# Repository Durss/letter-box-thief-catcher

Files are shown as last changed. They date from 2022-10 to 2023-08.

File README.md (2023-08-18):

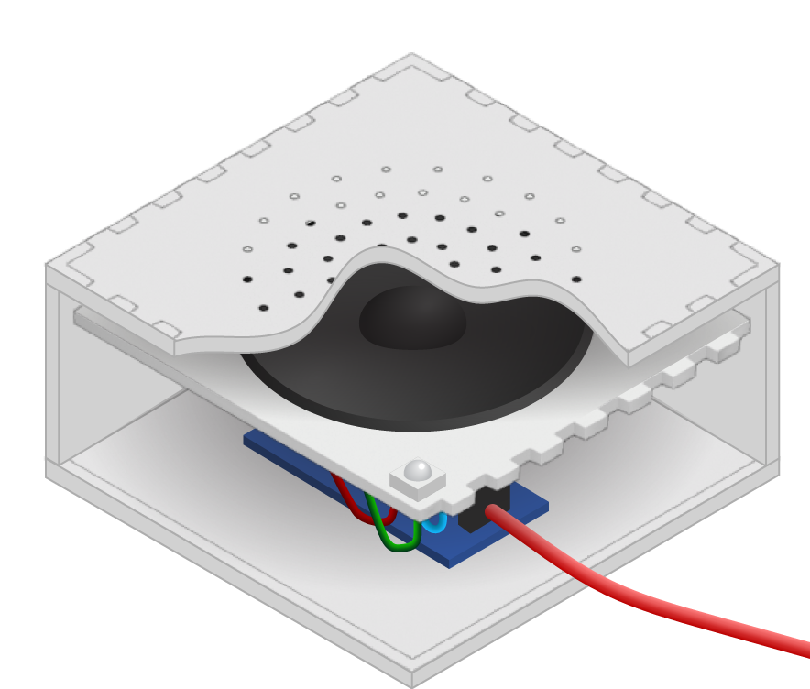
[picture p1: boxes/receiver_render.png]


# Da heck is that?
A thief is starting to hammer my balls stealing stuff from the mailboxes of my building, including mine.\
Stealing my credit card being the red line he shoudln't have crossed, and as we say `Don't fuck with a developer`, I've made this simple arduino project consisting of a BLE emiter I put inside the mailbox and a receiver inside my flat.\
When the mailbox is opened, the receiver knows and screams sounds on a speaker.\
As soon as the receiver screams, I'll run down and god knows what will happen then!\
\
It's made to use as low energy as possible so it can run for weeks on a Lipo battery.\
There is no actual BLE connection, the emitter simply changes the bluetooth connexion name to `letterbox-open` or `letterbox-closed` depending on the door state.\
It goes to deep sleep for 2 minutes and wakes up for only 10s just to tell the receivier that battery is still alive.\
If the door is opened when in deep sleep, an interrupt wakes the board up so the receiver knows the door has been opened as fast as possible.\
\
I'm lucky enough to get my flat just above the mailboxes so the bluetooth connection can be established between the mailbox and my home.\
If you don't, this won't help you for this use case but it may for something else, who knows...

# Component parts
- 1 [Particle Xenon](https://docs.particle.io/xenon/) board. These are discontinued, but it should run on any other kind of [Particle Boards](https://www.particle.io/devices/) as long as it supports bluetooth and can most probably run on ESP32 boards with probably some tweaks.
- 1 [speaker](https://www.adafruit.com/product/1313).
- 1 [DFPlayer mini](https://wiki.dfrobot.com/DFPlayer_Mini_SKU_DFR0299) that plays MP3s on the speaker.
- 1 [lipo battery](https://www.adafruit.com/product/2011) to power the board. The boards includes a lipo charger, just plug it to a USB wall adapter.
- 1 [micro switch](https://www.sparkfun.com/products/13014) that detects the door opening and wakes up the arduino board.
- 1 [Piranha RGB LED](https://www.adafruit.com/product/1451) (or any RGB led but it might not fit in the [given box](#boxes)
- 1 micro SD card to store MP3s
- 3 resistors (330Ω)
- [Optional] 1 or 2 [bluetooth antennas](https://www.adafruit.com/product/2308) to expand bluetooth range *(the one linked is for wifi but it should work also for BLE)*
- [Optional] 1 [protoboard](https://www.adafruit.com/product/4786) to solder components on it ([see schematics](#schematics))
- [Optional] [headers](https://www.adafruit.com/product/4160) if you don't want to solder the arduino board and the DFPlayer mini on the protoboard.

# Build
Build and upload emitter and receiver codes on their Xenon board.\
For that, you may want to use [VSCode](https://code.visualstudio.com) with [Particle Workbench](https://www.particle.io/workbench/).\
Also install [Particle CLI](https://docs.particle.io/getting-started/developer-tools/cli/) that installs necessary drivers.\

# Flash particle board
Open "Emitter" or "Receiver" folders in VScode. Not the root folder.\
Plug the board via USB, press `Ctrl+Shift+P` and select `Particle: Flash application (local)`. This will flash the board. Use `Particle: Serial monitor to get logs`.

# Boxes
If you have access to a laser cutter, you'll find SVG files to cut boxes for the emitter and the receiver under [boxes](https://github.com/Durss/mailbox-thief-catcher/tree/main/boxes) folder.

## Emiter:
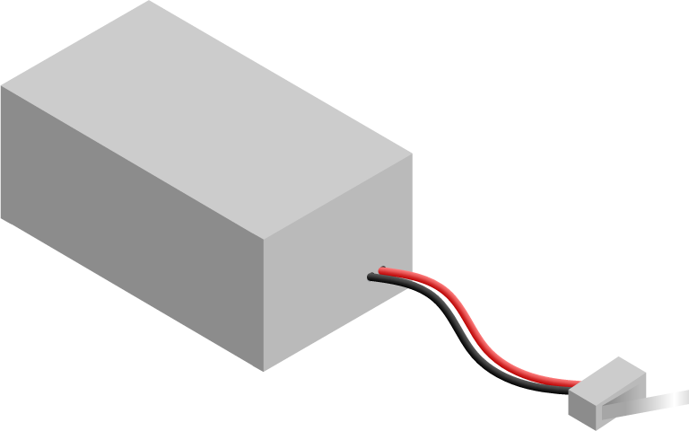
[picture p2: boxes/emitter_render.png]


## Receiver:


# Schematics
## Receiver
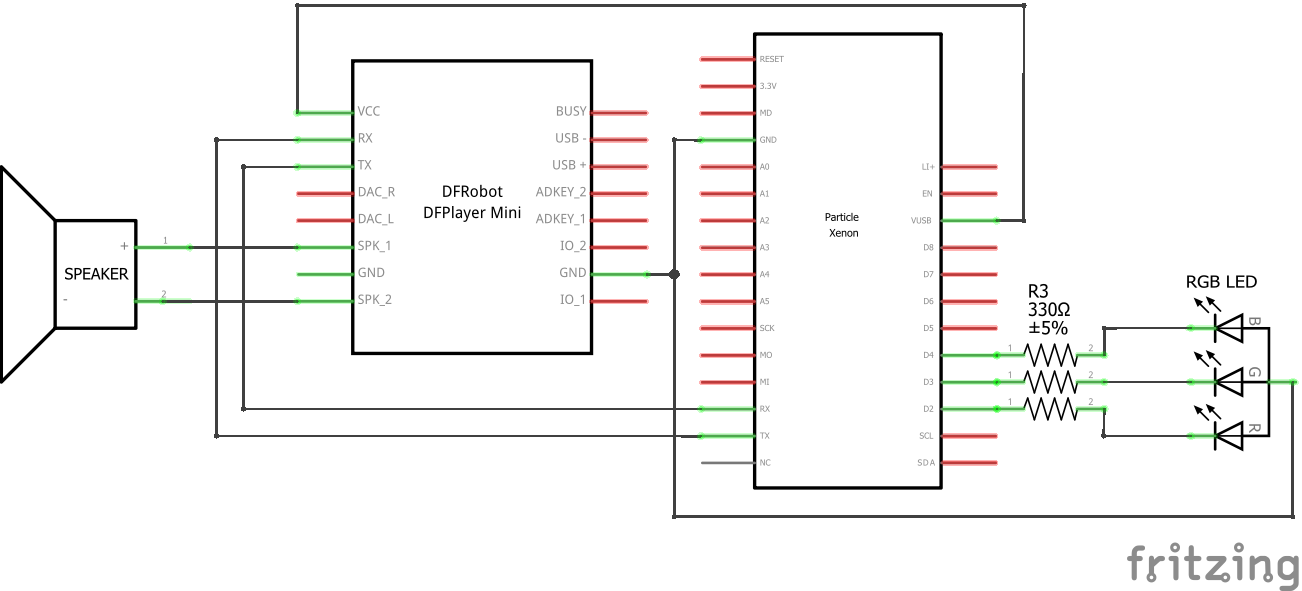
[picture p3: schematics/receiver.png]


## Emitter
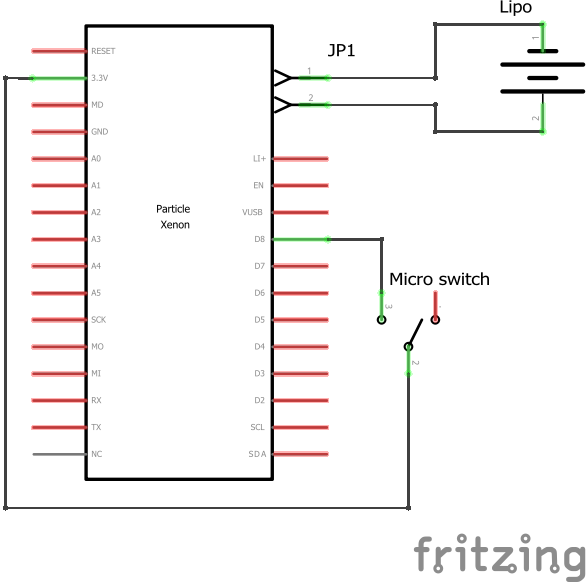
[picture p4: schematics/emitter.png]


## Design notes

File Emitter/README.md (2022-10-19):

# Emitter

A Particle project named Emitter

## Welcome to your project!

Every new Particle project is composed of 3 important elements that you'll see have been created in your project directory for Emitter.

#### ```/src``` folder:  
This is the source folder that contains the firmware files for your project. It should *not* be renamed. 
Anything that is in this folder when you compile your project will be sent to our compile service and compiled into a firmware binary for the Particle device that you have targeted.

If your application contains multiple files, they should all be included in the `src` folder. If your firmware depends on Particle libraries, those dependencies are specified in the `project.properties` file referenced below.

#### ```.ino``` file:
This file is the firmware that will run as the primary application on your Particle device. It contains a `setup()` and `loop()` function, and can be written in Wiring or C/C++. For more information about using the Particle firmware API to create firmware for your Particle device, refer to the [Firmware Reference](https://docs.particle.io/reference/firmware/) section of the Particle documentation.

#### ```project.properties``` file:  
This is the file that specifies the name and version number of the libraries that your project depends on. Dependencies are added automatically to your `project.properties` file when you add a library to a project using the `particle library add` command in the CLI or add a library in the Desktop IDE.

## Adding additional files to your project

#### Projects with multiple sources
If you would like add additional files to your application, they should be added to the `/src` folder. All files in the `/src` folder will be sent to the Particle Cloud to produce a compiled binary.

#### Projects with external libraries
If your project includes a library that has not been registered in the Particle libraries system, you should create a new folder named `/lib/<libraryname>/src` under `/<project dir>` and add the `.h`, `.cpp` & `library.properties` files for your library there. Read the [Firmware Libraries guide](https://docs.particle.io/guide/tools-and-features/libraries/) for more details on how to develop libraries. Note that all contents of the `/lib` folder and subfolders will also be sent to the Cloud for compilation.

## Compiling your project

When you're ready to compile your project, make sure you have the correct Particle device target selected and run `particle compile <platform>` in the CLI or click the Compile button in the Desktop IDE. The following files in your project folder will be sent to the compile service:

- Everything in the `/src` folder, including your `.ino` application file
- The `project.properties` file for your project
- Any libraries stored under `lib/<libraryname>/src`

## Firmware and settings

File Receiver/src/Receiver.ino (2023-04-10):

#include "Particle.h"

SYSTEM_THREAD(ENABLED);
SYSTEM_MODE(MANUAL);

#define MP3_Start_Byte 0x7E
#define MP3_Version_Byte 0xFF
#define MP3_Command_Length 0x06
#define MP3_End_Byte 0xEF
#define MP3_Acknowledge 0x00 //Returns info with command 0x41 [0x01: info, 0x00: no info]

const uint LOST_TIMEOUT = 6 * 60 * 1000;//Duration after which the emitter is considered lost if it didn't show up
const char *BLE_OPENED_NAME = "letterbox-opened";//BLE name when door is opened
const char *BLE_CLOSED_NAME = "letterbox-closed";//BLE name when door is closed

// EXAMPLE
BleScanParams scanParams;


bool doorOpened = false;
bool toogle = true;
uint lastAliveMs = 0;
int rPin = D2;
int gPin = D3;
int bPin = D4;

void setup()
{
	Serial.begin(9600);
	Serial1.begin(9600);
	Serial.println("Serial begin");
	/*
	// delay(2000);
	Serial.println("Init player");
	MP3ExecuteCmd(0x3F, 0, 0); // Send request for initialization parameters

	// Wait until initialization parameters are received (10 bytes)
	while (Serial1.available() < 10)
	{
		Serial.println(Serial1.read());
		delay(100); // Pretty long delays between succesive commands needed (not always the same)
	}
	//*/
	
	scanParams.active = 0;
	scanParams.size = sizeof(BleScanParams);
	int res = BLE.getScanParameters(&scanParams);
	Serial.print("RESULT: ");
	Serial.println(res);

	pinMode(rPin, OUTPUT);
	pinMode(gPin, OUTPUT);
	pinMode(bPin, OUTPUT);

	analogWrite(rPin, 0);
	analogWrite(gPin, 255);
	analogWrite(bPin, 255);

	MP3ExecuteCmd(0x06, 0, 25);//Set volume from 0 to 33

	analogWrite(rPin, 0);
	analogWrite(gPin, 0);
	analogWrite(bPin, 0);

	Serial.println("Play sound");
	MP3ExecuteCmd(0x0F, 1, 1);//Play start sound
	delay(2000);
}

void loop()
{
	/* Demo mode
	delay(5000);
	analogWrite(rPin, 0);
	analogWrite(gPin, 255);
	analogWrite(bPin, 255);
	delay(500);
	MP3ExecuteCmd(0x0F, 1, 2);//Play sound N°1

	delay(5000);

	analogWrite(rPin, 0);
	analogWrite(gPin, 0);
	analogWrite(bPin, 0);
	//*/

	//*
	MP3OnMessage();

	if(millis() - lastAliveMs > LOST_TIMEOUT) {
		Serial.println("Device lost !!");
		MP3ExecuteCmd(0x0F, 1, 3);//Play sound N°2
		MP3ExecuteCmd(0x19, 0, 0);//Loop sound
		analogWrite(rPin, 255);
		analogWrite(gPin, 0);
		analogWrite(bPin, 0);
	}
	
	Serial.println("Start scan...");
	if(!doorOpened) {
		toogle = !toogle;
		if(toogle) {
			analogWrite(rPin, 255);
			analogWrite(gPin, 250);
			analogWrite(bPin, 253);
		}else{
			analogWrite(rPin, 255);
			analogWrite(gPin, 253);
			analogWrite(bPin, 252);
		}
	}
	//Scan for devices
	(void) BLE.scan(scanResultCallback, NULL);
	delay(1000);
	//*/
}

void scanResultCallback(const BleScanResult *scanResult, void *context)
{
	// Serial.println("Scan result...");
	String name = scanResult->advertisingData.deviceName();
	
	if(name.length() > 0) {
		//Check if a BLE device has the name open name
		if(name == BLE_OPENED_NAME) {
			Serial.println("Box opened");
			doorOpened = true;
			lastAliveMs = millis();
			analogWrite(rPin, 0);
			analogWrite(gPin, 255);
			analogWrite(bPin, 255);
			delay(500);
			MP3ExecuteCmd(0x0F, 1, 2);//Play sound N°1
			// MP3ExecuteCmd(0x19, 0, 0);//Loop sound
			BLE.stopScanning();
		}else
		if(name == BLE_CLOSED_NAME) {
			Serial.println("Box closed");
			doorOpened = false;
			analogWrite(rPin, 255);
			analogWrite(gPin, 240);
			analogWrite(bPin, 255);
			delay(500);
			lastAliveMs = millis();
			BLE.stopScanning();
		}
	}
}

void MP3ExecuteCmd(byte CMD, byte Par1, byte Par2) // Excecute the command and parameters
{
	// Calculate the checksum (2 bytes)
	int16_t checksum = -(MP3_Version_Byte + MP3_Command_Length + CMD + MP3_Acknowledge + Par1 + Par2);

	// Build the command line
	byte Command_line[10] = {MP3_Start_Byte, MP3_Version_Byte, MP3_Command_Length, CMD, MP3_Acknowledge, Par1, Par2, checksum >> 8, checksum & 0xFF, MP3_End_Byte};

	//Send the command line to the module
	for (byte k = 0; k < 10; k++)
	{
		Serial1.write(Command_line[k]);
	}
}

void MP3OnMessage()
{
	if (Serial1.available() >= 10) // There is at least 1 returned message (10 bytes each)
	{
		// Read the returned code
		byte Returned[10];
		for (byte k = 0; k < 10; k++) Returned[k] = Serial1.read();

		// Wtite the returned code to the screen
		Serial.print("Returned: 0x"); if (Returned[3] < 16) Serial.print("0"); Serial.print(Returned[3],HEX);
		Serial.print("("); Serial.print(Returned[3], DEC);
		Serial.print("); Parameter: 0x"); if (Returned[5] < 16) Serial.print("0"); Serial.print(Returned[5],HEX);
		Serial.print("("); Serial1.print(Returned[5], DEC);
		Serial.print("), 0x"); if (Returned[6] < 16) Serial.print("0"); Serial.print(Returned[6],HEX);
		Serial.print("("); Serial.print(Returned[6], DEC); Serial.println(")");
	}
}

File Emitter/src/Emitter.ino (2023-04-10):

#include "Particle.h"

SYSTEM_MODE(MANUAL);

const uint MICRO_SWITCH_PIN = WKP;
const uint CLOSED_DURATION_SLEEP = 10;// If the door stays closed for this number of seconds, the boards goes to sleep
const long SLEEP_DURATION = 60;// Number of seconds the board goes to sleep after the door stayed closed
const char *BLE_OPENED_NAME = "letterbox-opened";// Name of the BLE device when door is openeed
const char *BLE_CLOSED_NAME = "letterbox-closed";// Name of the BLE device when door is closed
const char *BLE_UUID = "4f2cb1d0-c600-40f0-8d23-94643bbb65ce";// BlueTooth service ID

bool closed = false;
uint closed_at = 0;

void setup()
{
	Serial1.begin(9600);
	RGB.control(true);

	// pinMode(reedPin, INPUT_PULLUP);
	pinMode(PWR, INPUT);
	pinMode(CHG, INPUT);
	RGB.color(0,0,0);
	
	// attachInterrupt(WKP, doorInterruptHandler, RISING);

	advertiseCurrentState(true);

	pinMode(WKP, INPUT_PULLDOWN);
	Serial.println(digitalRead(WKP));
	if(digitalRead(WKP) == LOW) {
		System.sleep(D8, RISING, SLEEP_DURATION);
		// System.sleep(SLEEP_MODE_DEEP, SLEEP_DURATION);
	}
}

void loop()
{
	advertiseCurrentState(false);

	if(closed && millis() - closed_at > CLOSED_DURATION_SLEEP * 1000) {
		if(digitalRead(WKP) == LOW) {
			//Door closed for the last CLOSED_DURATION_SLEEP seconds.
			//Go to deep sleep and wake up in SLEEP_DURATION seconds.
			//If door is opened it will also wake up the board.
			Serial.print("zzz Nap time for ");
			Serial.println(SLEEP_DURATION);
			// System.sleep(SLEEP_MODE_DEEP, SLEEP_DURATION);
			System.sleep(D8, RISING, SLEEP_DURATION);
			//delay(10000);//Leave it time to the receiver to detect us
		}
	}

	delay(500);
}

void advertiseCurrentState(bool isInit) {
	bool doorOpened = digitalRead(MICRO_SWITCH_PIN) == 0 ? false : true;

	// long batteryPercent = digitalRead(PWR) && !digitalRead(CHG);
	// Serial.print("Charging? ");
	// Serial.println(batteryPercent);

	BleAdvertisingData advData;
	if (doorOpened) {
		closed = false;
		closed_at = millis();
		Serial.println("Door opened");
		advData.appendLocalName(BLE_OPENED_NAME);
	}else{
		Serial.print("Door closed - WKP state:");
		Serial.println(digitalRead(WKP) );
		advData.appendLocalName(BLE_CLOSED_NAME);
		if(!closed) {
			closed_at = millis();
			closed = true;
		}
	}
	advData.appendServiceUUID(BLE_UUID);
	//Update advertising label
	if(isInit) {
		BLE.setAdvertisingData(&advData);
	}else{
		BLE.setAdvertisingInterval(50);
		BLE.advertise(&advData);
	}
}

// void doorInterruptHandler() {
// 	Serial.print("Door state changed:");
// 	closed = digitalRead(reedPin) == 0 ? false : true;
// 	closed_at = millis();
// 	if(closed) Serial.println(" closed");
// 	else       Serial.println(" opened");
// }

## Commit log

2022-10-19 removing useless interrupt
2022-10-19 Adding status LED an boot sound Adding sdcard content
2022-10-19 Renaming sensor var
2022-10-19 Update README.md
    replacing reed switch by a micro switch
2022-10-19 adding schematics
    [emitter.fzz, receiver.fzz]
2022-10-19 Adding laser cut files
2022-10-19 adding RGB LED
2022-10-19 Adding schematics and ISO renders
2022-10-20 Reducing volume and LED brightness
2022-10-20 Removing useless flag + toggling led color during scan
